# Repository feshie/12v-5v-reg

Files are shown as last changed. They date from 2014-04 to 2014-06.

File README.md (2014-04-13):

12v-5v-reg
==========

A switched 12Volt to 5Volt regulator

Will take a nominal 12v in (designed for a lead acid) and produced a regulated 5v supply capable of supplying 2A.

The onboard LEDs show the prescenec of 12V, the switch status, and the prescence of the 5V output.  These LEDs can be disabled to minimise power usage

There is a bypass jumper to enable the output to remain active independently of the enable status.

The enable pins will turn the output on high.

This board has yet to be built and tested so should be considered in alpha status.

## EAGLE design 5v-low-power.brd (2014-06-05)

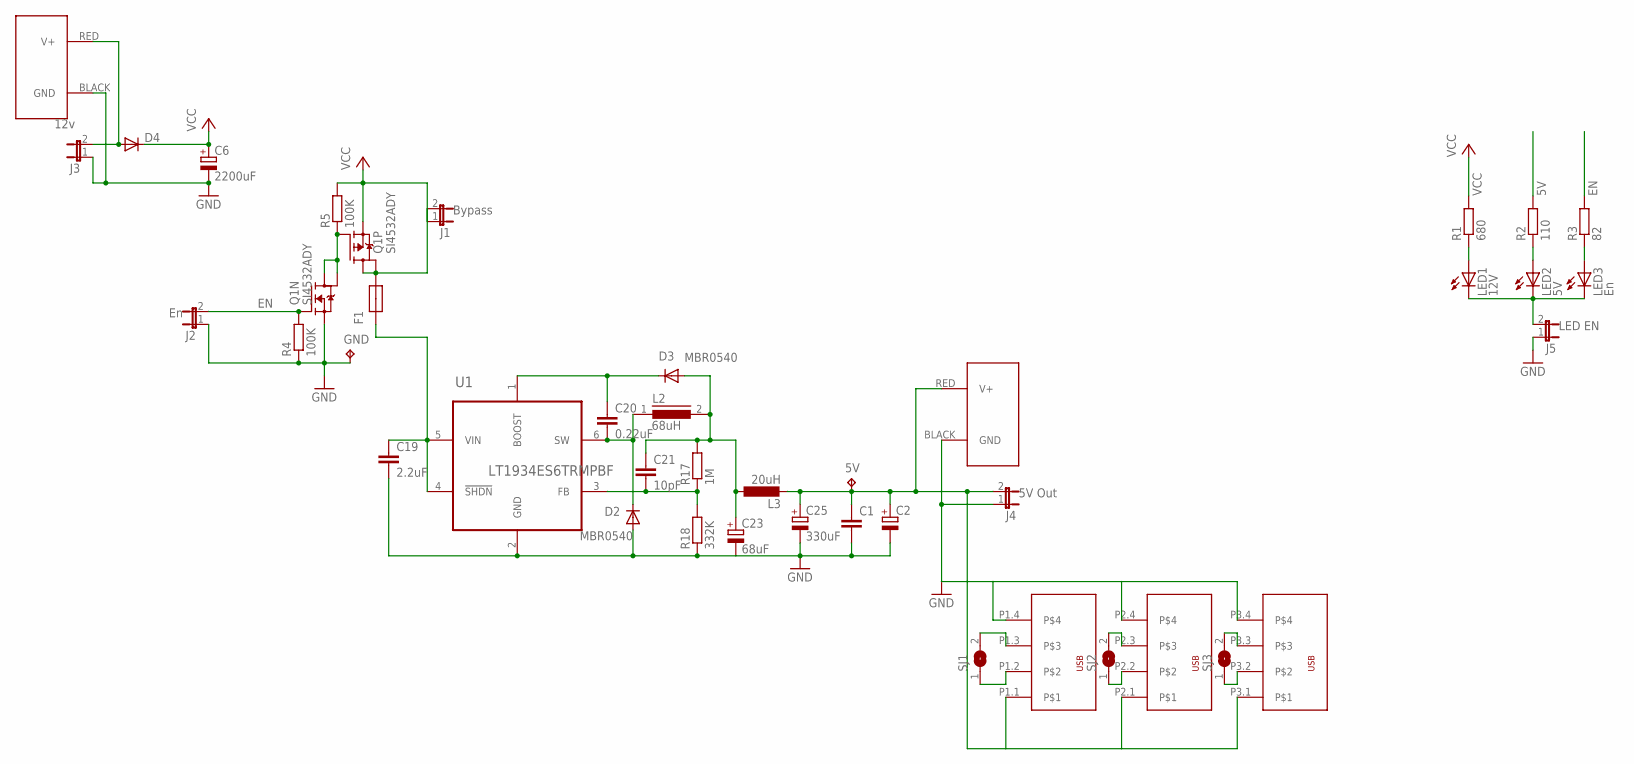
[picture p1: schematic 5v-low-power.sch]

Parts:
5V: 5V B; B1,27
C1: C-EUC0805; C0805
C2: CPOL-EUB/3528-21R; B/3528-21R
C6: 2200uF; E5-13
C19: 2.2uF; C0805
C20: 0.22uF; C0805
C21: 10pF; C0805
C23: 68uF; PANASONIC_E
C25: 330uF; E5-8,5
D2, D3: MBR0540; SOD123
D4: DIODE-SMB; SMB
F1: MF-MSMF110; 1812
GND: 5V B; B1,27
J1: Bypass; 2-MOLEX
J2: En; 2-MOLEX
J3: 12v; 2-MOLEX
J4: 5V Out; 2-MOLEX
J5: LED EN; 2-MOLEX
J6, J7: POWERPOLE_POWER25A; POWERPOLE_PAIR_25A
L2: 68uH; DR127
L3: 20uH; 6000-XXXX-RC
LED1: 12V; CHIP-LED0805
LED2: 5V; CHIP-LED0805
LED3: En; CHIP-LED0805
Q1: SI4532ADY; SO8
R1: 680; R0805
R2: 110; R0805
R3: 82; R0805
R4, R5: 100K; R0805
R17: 1M; R0805
R18: 332K; R0805
SJ1, SJ2, SJ3: SJ
U1: LT1934ES6TRMPBF; SOT95P280X100-6N
U$1: USB_DUAL_VERT+HORIZTRIPPLE; USB_DUAL_HORIZ+VERT

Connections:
5V: 5V.TP, C1.1, C2.+, C25.+, J4.2, J6.RED (V+), L3.2, R2.2, U$1.P1.1, U$1.P2.1, U$1.P3.1
EN: J2.2, Q1.2 (G), R3.2, R4.2
GND: C1.2, C2.-, C6.-, C19.2, C23.-, C25.-, D2.A, GND.TP, J2.1, J3.1, J4.1, J5.1, J6.BLACK (GND), J7.BLACK (GND), Q1.1 (S), R4.1, R18.1, U1.2 (GND), U$1.P1.4, U$1.P2.4, U$1.P3.4
LEDGND1: J5.2, LED1.C, LED2.C, LED3.C
unnamed: LED1.A, R1.1
unnamed: SJ1.2, U$1.P1.3
unnamed: D4.A, J3.2, J7.RED (V+)
unnamed: SJ1.1, U$1.P1.2
unnamed: SJ2.1, U$1.P2.2
unnamed: SJ2.2, U$1.P2.3
unnamed: SJ3.2, U$1.P3.3
unnamed: SJ3.1, U$1.P3.2
unnamed: Q1.4 (G), Q1.7 (D), Q1.8 (D), R5.1
unnamed: LED2.A, R2.1
unnamed: LED3.A, R3.1
unnamed: C20.2, D2.C, L2.1, U1.6 (SW)
unnamed: F1.2, J1.2, Q1.5 (D), Q1.6 (D)
unnamed: C21.1, C23.+, D3.A, L2.2, L3.1, R17.2
unnamed: C20.1, D3.C, U1.1 (BOOST)
unnamed: C21.2, R17.1, R18.2, U1.3 (FB)
VCC: C6.+, D4.C, J1.1, Q1.3 (S), R1.2, R5.2
VCC_HP2_SW: C19.1, F1.1, U1.4 (!SHDN), U1.5 (VIN)

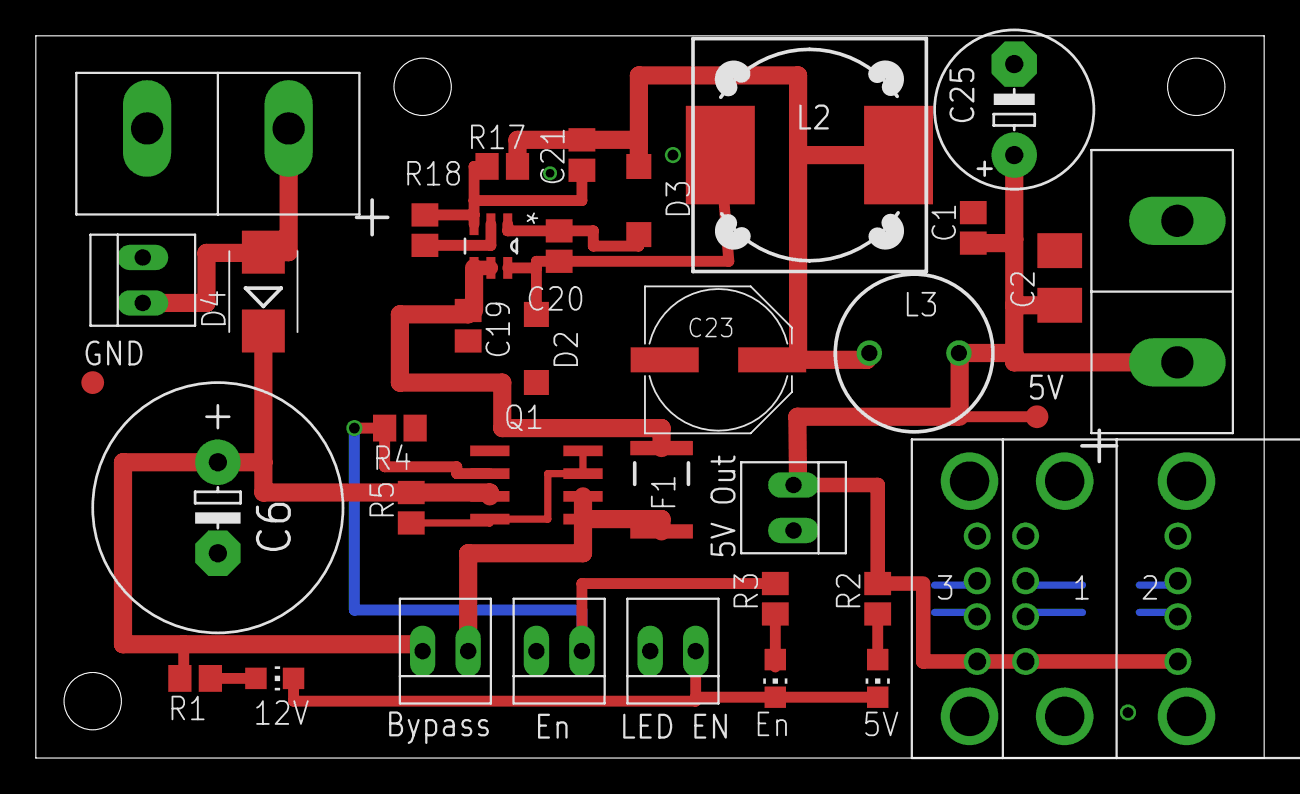
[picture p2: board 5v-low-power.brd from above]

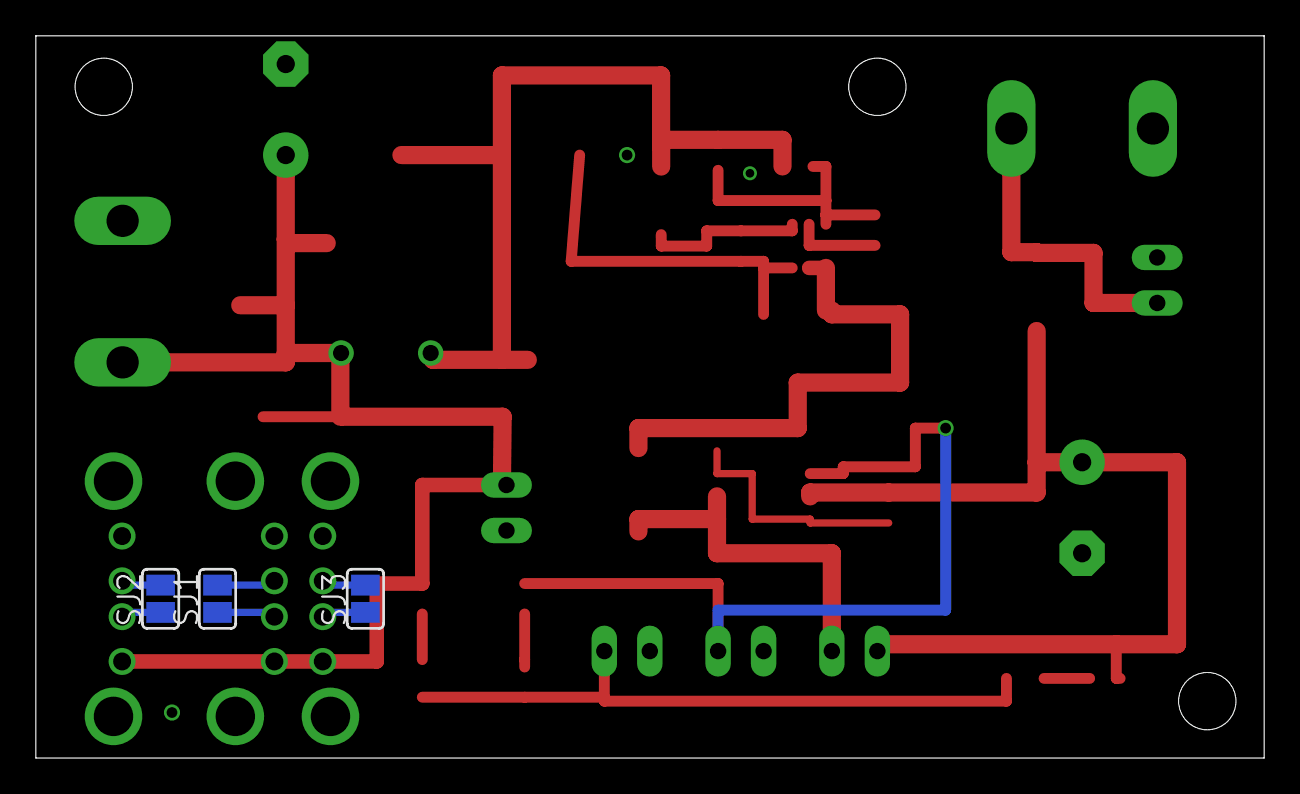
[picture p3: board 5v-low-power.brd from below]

Board: 2 copper layers, 68.6 x 40.3 mm, 39 parts (3 on the bottom side), 22 nets.

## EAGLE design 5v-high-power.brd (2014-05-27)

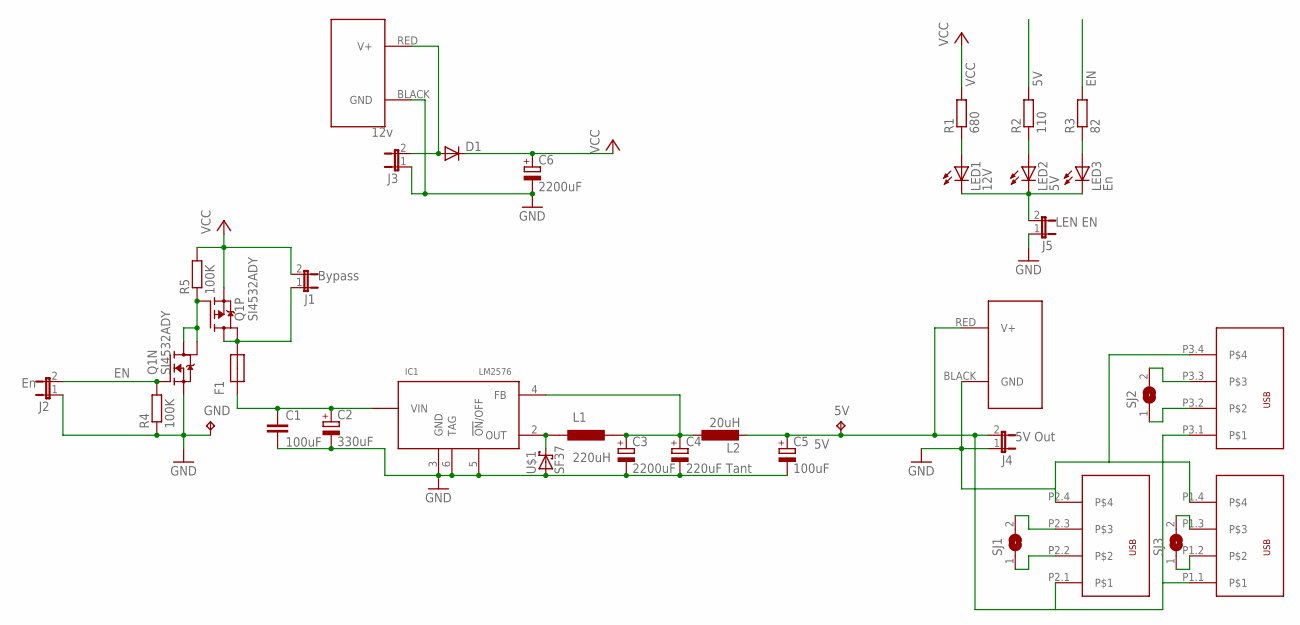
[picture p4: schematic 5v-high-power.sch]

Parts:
5V: 5V B; B1,27
C1: 100uF; C1210K
C2: 330uF; E5-8,5
C3, C6: 2200uF; E5-13
C4: 220uF Tant; B/3528-21R
C5: 100uF; PANASONIC_E
D1: DIODE-SMB; SMB
F1: MF-MSMF110; 1812
GND: 5V B; B1,27
IC1: LM2576; TO263
J1: Bypass; 2-MOLEX
J2: En; 2-MOLEX
J3: 12v; 2-MOLEX
J4: 5V Out; 2-MOLEX
J5: LEN EN; 2-MOLEX
J6, J7: POWERPOLE_POWER25A; POWERPOLE_PAIR_25A
L1: 220uH; DR127
L2: 20uH; 6000-XXXX-RC
LED1: 12V; CHIP-LED0805
LED2: 5V; CHIP-LED0805
LED3: En; CHIP-LED0805
Q1: SI4532ADY; SO8
R1: 680; R0805
R2: 110; R0805
R3: 82; R0805
R4, R5: 100K; R0805
SJ1, SJ2, SJ3: SJ
U$1: SF37; DO-201AD
U$2: USB_DUAL_VERT+HORIZTRIPPLE; USB_DUAL_HORIZ+VERT

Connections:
5V: 5V.TP, C5.+, J4.2, J6.RED (V+), L2.2, R2.2, U$2.P1.1, U$2.P2.1, U$2.P3.1
EN: J2.2, Q1.2 (G), R3.2, R4.2
GND: C1.2, C2.-, C3.-, C4.-, C5.-, C6.-, GND.TP, IC1.3 (GND), IC1.5 (!ON!/OFF), IC1.6 (TAG), J2.1, J3.1, J4.1, J5.1, J6.BLACK (GND), J7.BLACK (GND), Q1.1 (S), R4.1, U$1.2 (A), U$2.P1.4, U$2.P2.4, U$2.P3.4
LEDGND: J5.2, LED1.C, LED2.C, LED3.C
unnamed: D1.A, J3.2, J7.RED (V+)
unnamed: LED1.A, R1.1
unnamed: SJ1.2, U$2.P2.3
unnamed: SJ1.1, U$2.P2.2
unnamed: SJ2.2, U$2.P3.3
unnamed: SJ2.1, U$2.P3.2
unnamed: SJ3.2, U$2.P1.3
unnamed: SJ3.1, U$2.P1.2
unnamed: Q1.4 (G), Q1.7 (D), Q1.8 (D), R5.1
unnamed: LED2.A, R2.1
unnamed: LED3.A, R3.1
unnamed: F1.2, J1.1, Q1.5 (D), Q1.6 (D)
unnamed: C3.+, C4.+, IC1.4 (FB), L1.2, L2.1
unnamed: IC1.2 (OUT), L1.1, U$1.1 (C)
VCC: C6.+, D1.C, J1.2, Q1.3 (S), R1.2, R5.2
VCC_HP2_SW: C1.1, C2.+, F1.1, IC1.1 (VIN)

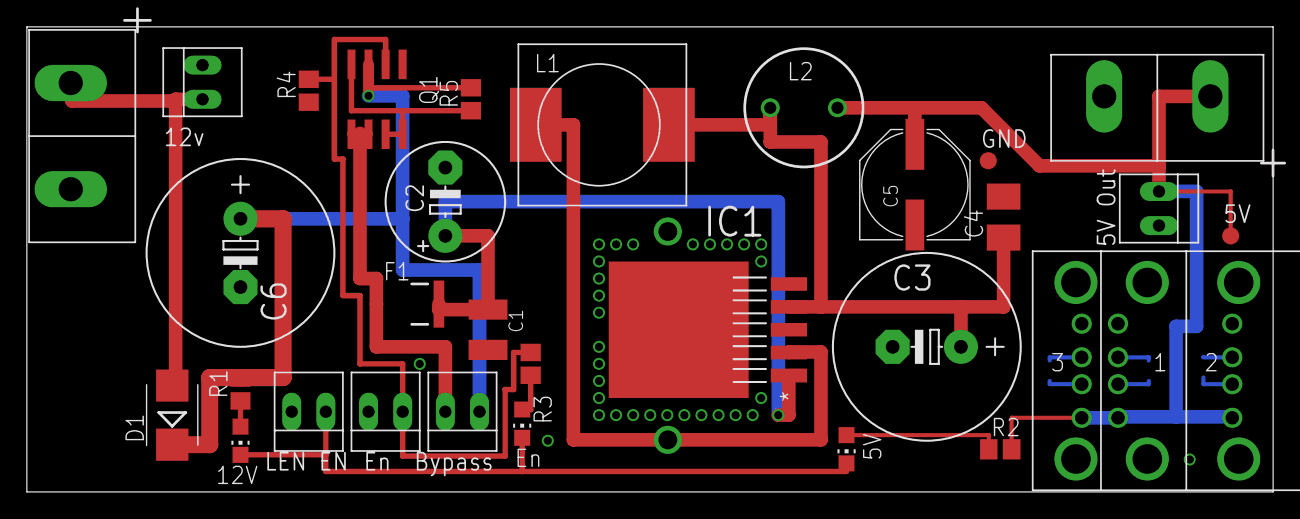
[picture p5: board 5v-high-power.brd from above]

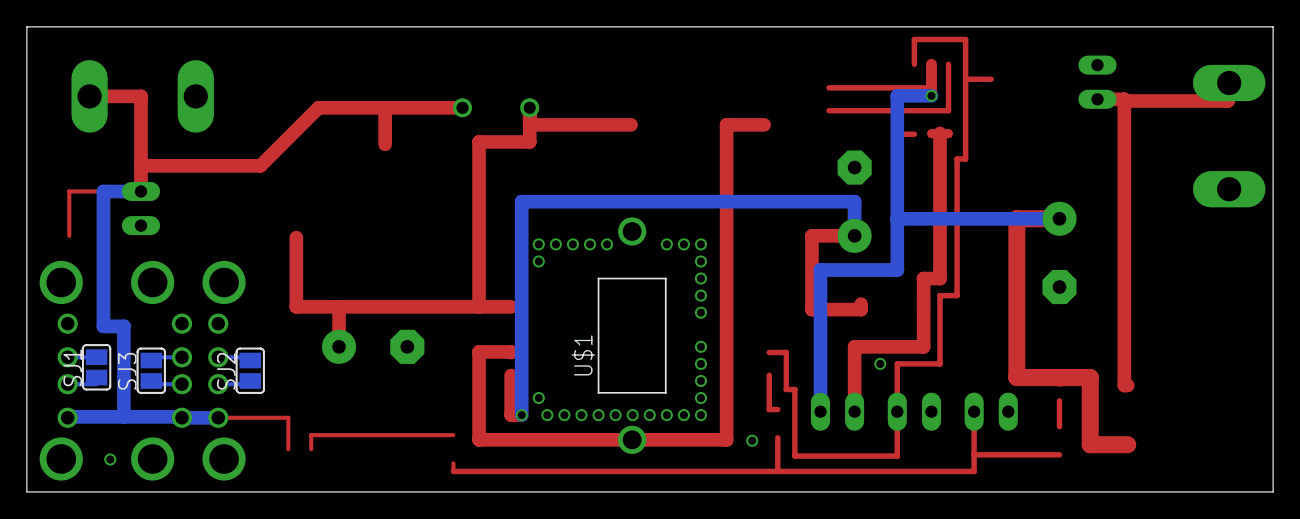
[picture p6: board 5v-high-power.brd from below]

Board: 2 copper layers, 92.7 x 34.6 mm, 34 parts (4 on the bottom side), 20 nets.

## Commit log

2014-04-13 First version using molex KK as the power input
    [5v-power.brd, 5v-power.sch]
2014-04-29 power pole in and out now added
    [5v-power.brd, 5v-power.sch]
2014-05-02 Existing boards renamed to allow addition of low power
    [5v-high-power.brd, 5v-high-power.sch]
2014-05-02 First version of low power switched board
    [5v-low-power.brd, 5v-low-power.sch]
2014-05-02 changed to correct powerpole version added current rating onto docu layer
    [5v-high-power.brd, 5v-high-power.sch, 5v-low-power.brd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]
2014-05-13 Added additional USB footprints and rotated some powerpoles
    [5v-high-power.brd, 5v-high-power.sch, 5v-low-power.brd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]
2014-05-13 moved a couple of components
    [5v-high-power.brd]
2014-05-13 minor silk screen tweaks
    [5v-high-power.brd, 5v-low-power.brd]
2014-05-14 bump version number for hackvana regeneration
    [5v-high-power.brd, 5v-low-power.brd]
2014-05-27 cutter changed to 0.15mm
    [5v-high-power.brd, 5v-low-power.brd]
2014-06-05 now uses DR127 footprint for big inductor
    [5v-low-power.brd, 5v-low-power.sch]
2014-06-05 Added more smoothing caps
    [5v-low-power.brd, 5v-low-power.sch]
